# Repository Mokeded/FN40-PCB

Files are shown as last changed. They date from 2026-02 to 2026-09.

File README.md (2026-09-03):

# FN40 PCB

KiCad PCB design for the **FN40**, a hotswap 40%-style mechanical keyboard (internal project name `4060`).

## Contents

- `4060.kicad_pro` / `4060.kicad_sch` / `4060.kicad_pcb` — KiCad project, schematic, and board files
- `4060.kicad_prl` — KiCad project local settings
- `4060.json` — layout/keyboard-layout-editor data
- `4060.svg` — rendered board image
- `4060.round-tracks-config` — config for the KiCad round-tracks plugin
- `4060-backups/` — autosaved backups of the board file
- `footprints/Switch_Keyboard_Hotswap_Kailh.pretty/` — Kailh hotswap socket footprint library
- `acheron_Components.pretty-master/`, `acheron_Connectors.pretty-master/` — third-party footprint libraries from [Acheron](https://github.com/acheron-project) (also kept as `.zip` archives)
- `random-keyboard-parts.pretty/` — additional footprint library
- `fp-lib-table` / `fp-info-cache` — KiCad footprint library table and cache
- `fabrication-toolkit-options.json` — settings for the [KiCad Fabrication Toolkit](https://github.com/bennymeg/kicad-fabrication-toolkit) plugin used to generate manufacturing files
- `freerouting.dsn` / `temp-freerouting.dsn` — Specctra DSN exports for autorouting with [Freerouting](https://github.com/freerouting/freerouting)
- `kbplacer.log` — log output from the [KiCad KBPlacer](https://github.com/adamws/kicad-kbplacer) plugin used for switch placement
- `production/` — generated manufacturing outputs, including `4060.zip` (Gerbers/drill files), `bom.csv` (bill of materials), `positions.csv` (pick-and-place data), `designators.csv`, and `netlist.ipc`

## Getting started

1. Install [KiCad](https://www.kicad.org/) (developed with KiCad 7/8).
2. Open `4060.kicad_pro` in KiCad.
3. Footprint libraries referenced by `fp-lib-table` are included in this repo — no extra setup should be required.

## Fabrication

Manufacturing-ready files (Gerbers, drill files, BOM, and pick-and-place data) are available in `production/`. These were generated with the KiCad Fabrication Toolkit plugin; re-run it after any board changes to refresh the outputs.

## Credits

- Footprint libraries by [Acheron](https://github.com/acheron-project)
- Hotswap socket footprints from the [Switch_Keyboard_Hotswap_Kailh](https://github.com/) footprint library

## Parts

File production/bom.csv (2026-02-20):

Designator | Footprint | Quantity | Value | LCSC Part #
C1, C3, C4, C5, C6, C7 | 0402 | 6 | 100nF | C307331
C2 | 0402 | 1 | 4.7uF | C23733
C8, C9 | 0402 | 2 | 1uF | C52923
D1, D10, D11, D12, D13, D14, D15, D16, D17, D18, D19, D2, D20, D21, D22, D23, D24, D25, D26, D27, D28, D29, D3, D30, D31, D32, D33, D34, D35, D36, D37, D38, D39, D4, D40, D41, D42, D43, D44, D45, D46, D47, D48, D49, D5, D50, D51, D52, D53, D54, D55, D56, D57, D6, D7, D8, D9 | D_SOD-123F | 57 | D
J1 | MOLEX_781710004_MountingReliefs | 1 | JST | C588524
R1 | 0402 | 1 | 10k | C25744
SW1, SW10, SW11, SW13, SW14, SW15, SW16, SW17, SW18, SW19, SW2, SW20, SW21, SW22, SW25, SW26, SW27, SW28, SW29, SW3, SW30, SW31, SW32, SW33, SW34, SW37, SW38, SW39, SW4, SW40, SW41, SW42, SW43, SW44, SW45, SW46, SW5, SW50, SW51, SW55, SW56_1, SW6, SW7, SW8, SW9 | SW_Hotswap_Kailh_MX_Plated_1.00u | 45 | SW_Push
SW12, SW23, SW48, SW49, SW56, SW57 | SW_Hotswap_Kailh_MX_Plated_1.50u | 6 | SW_Push
SW24 | SW_Hotswap_Kailh_MX_Plated_1.75u_90deg | 1 | SW_Push
SW24_1 | SW_Hotswap_Kailh_MX_Plated_1.25u_90deg | 1 | SW_Push
SW35, SW36, SW48_1, SW57_1 | SW_Hotswap_Kailh_MX_Plated_1.25u | 4 | SW_Push
SW35_1 | SW_Hotswap_Kailh_MX_Plated_ISOEnter_270deg | 1 | SW_Push
SW35_2, SW36_1, SW54 | SW_Hotswap_Kailh_MX_Plated_2.25u | 3 | SW_Push
SW47 | SW_Hotswap_Kailh_MX_Plated_1.75u | 1 | SW_Push
SW47_1, SW52 | SW_Hotswap_Kailh_MX_Plated_2.75u | 2 | SW_Push
SW53 | SW_Hotswap_Kailh_MX_Plated_7.00u | 1 | SW_Push
SW58, SW59 | SW_SPST_SKQG_WithoutStem | 2 | RST | C318884
U1 | LQFP-48_7x7mm_P0.5mm | 1 | STM32F072C8Tx | C80488
U2 | SOT-23 | 1 | XC6206PxxxMR-Regulator_Linear | C5446

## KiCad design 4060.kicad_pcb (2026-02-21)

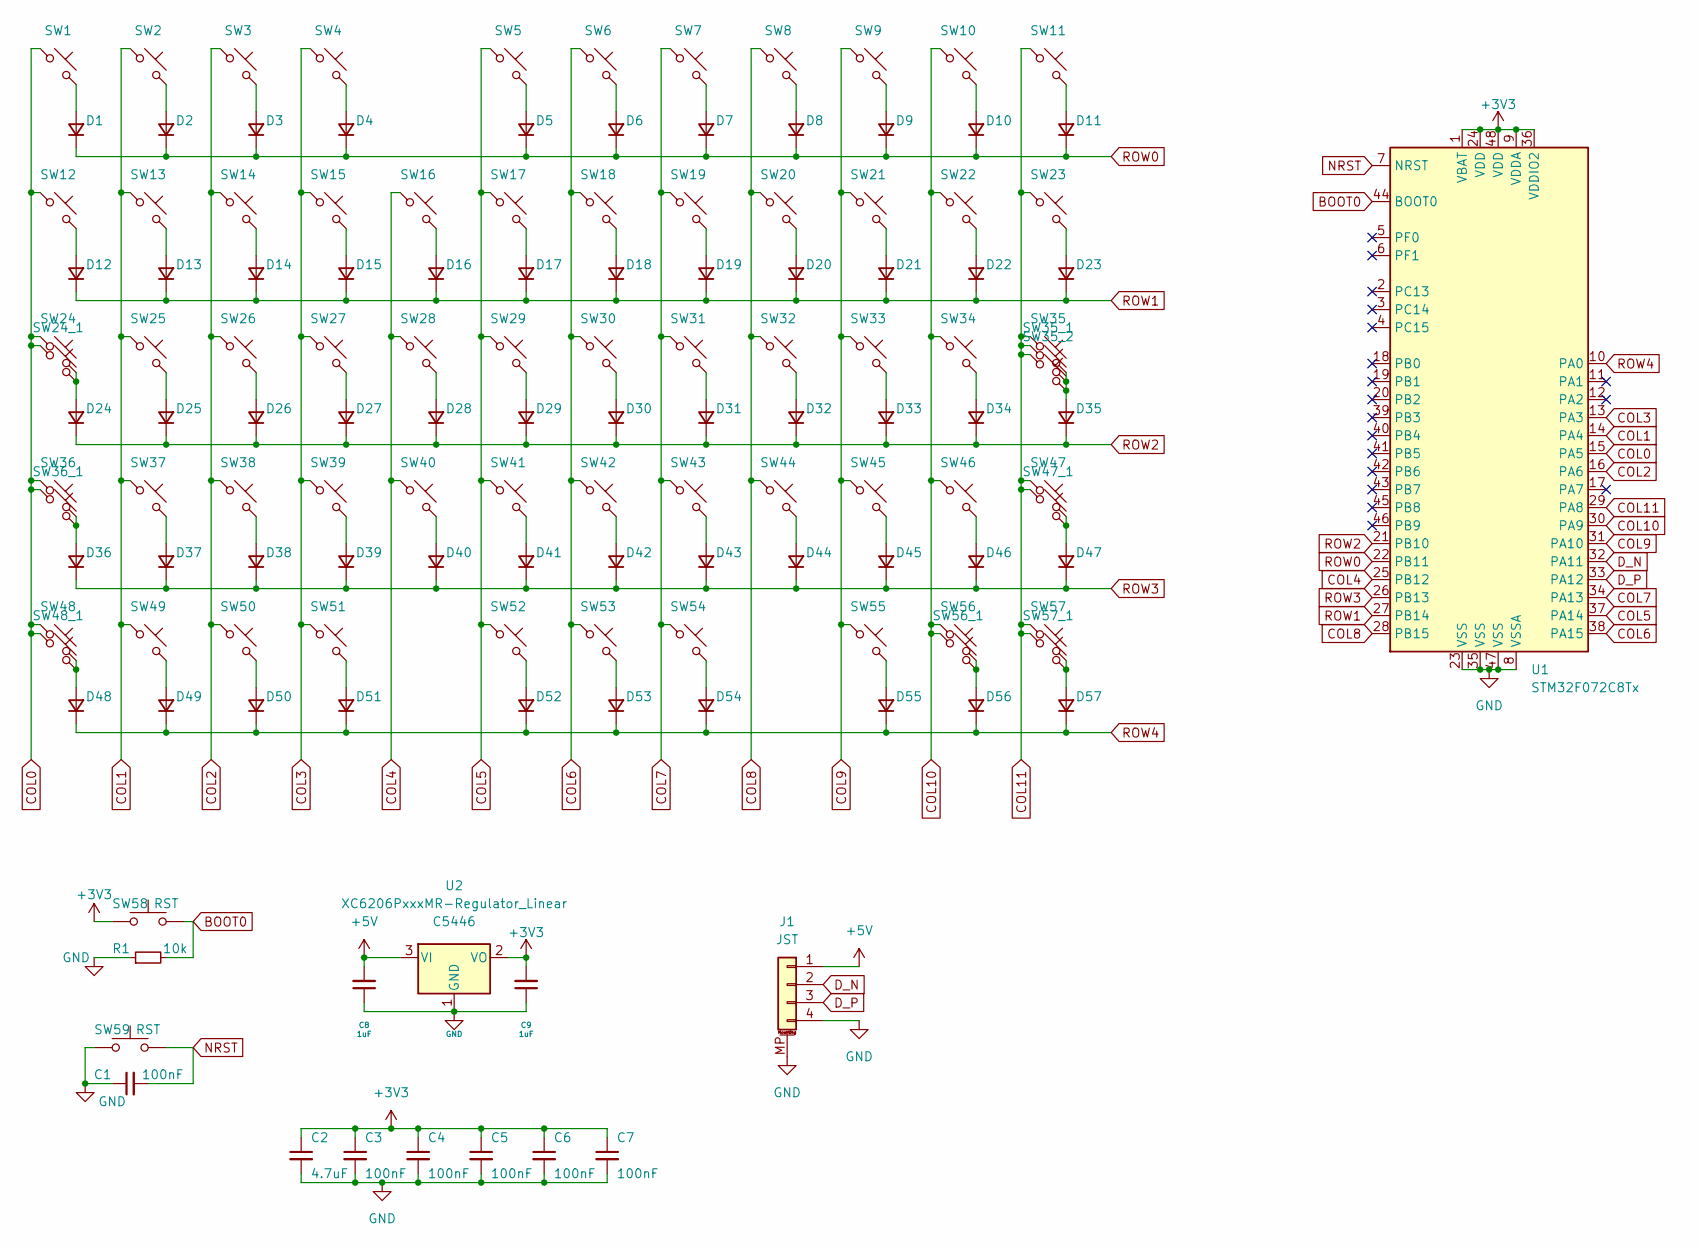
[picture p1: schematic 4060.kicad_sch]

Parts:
C1, C3, C4, C5, C6, C7: 100nF; C_0402_1005Metric; LCSC C307331
C2: 4.7uF; C_0402_1005Metric; LCSC C23733
C8, C9: 1uF; C_0402_1005Metric; LCSC C52923
D1, D2, D3, D4, D5, D6, D7, D8, D9, D10, D11, D12, D13, D14, D15, D16, D17, D18, D19, D20, D21, D22, D23, D24, D25, D26, D27, D28, D29, D30, D31, D32, D33, D34, D35, D36, D37, D38, D39, D40, D41, D42, D43, D44, D45, D46, D47, D48, D49, D50, D51, D52, D53, D54, D55, D56, D57: D; D_SOD-123F
J1: JST; MOLEX_781710004_MountingReliefs; LCSC C588524
R1: 10k; R_0402_1005Metric; LCSC C25744
SW1, SW2, SW3, SW4, SW5, SW6, SW7, SW8, SW9, SW10, SW11, SW13, SW14, SW15, SW16, SW17, SW18, SW19, SW20, SW21, SW22, SW25, SW26, SW27, SW28, SW29, SW30, SW31, SW32, SW33, SW34, SW37, SW38, SW39, SW40, SW41, SW42, SW43, SW44, SW45, SW46, SW50, SW51, SW55, SW56_1: SW_Push; SW_Hotswap_Kailh_MX_Plated_1.00u
SW12, SW23, SW48, SW49, SW56, SW57: SW_Push; SW_Hotswap_Kailh_MX_Plated_1.50u
SW24: SW_Push; SW_Hotswap_Kailh_MX_Plated_1.75u_90deg
SW24_1: SW_Push; SW_Hotswap_Kailh_MX_Plated_1.25u_90deg
SW35, SW36, SW48_1, SW57_1: SW_Push; SW_Hotswap_Kailh_MX_Plated_1.25u
SW35_1: SW_Push; SW_Hotswap_Kailh_MX_Plated_ISOEnter_270deg
SW35_2, SW36_1, SW54: SW_Push; SW_Hotswap_Kailh_MX_Plated_2.25u
SW47: SW_Push; SW_Hotswap_Kailh_MX_Plated_1.75u
SW47_1, SW52: SW_Push; SW_Hotswap_Kailh_MX_Plated_2.75u
SW53: SW_Push; SW_Hotswap_Kailh_MX_Plated_7.00u
SW58, SW59: RST; SW_SPST_SKQG_WithoutStem; LCSC C318884
U1: STM32F072C8Tx; LQFP-48_7x7mm_P0.5mm; LCSC C80488
U2: XC6206PxxxMR-Regulator_Linear; SOT-23; LCSC C5446

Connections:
+3V3: C2.1, C3.1, C4.1, C5.1, C6.1, C7.1, C9.2, SW58.1, U1.1 (VBAT), U1.9 (VDDA), U1.24 (VDD), U1.36 (VDDIO2), U1.48 (VDD), U2.2 (VO)
+5V: C8.2, J1.1, U2.3 (VI)
BOOT0: R1.2, SW58.2, U1.44 (BOOT0)
COL0: SW1.1, SW12.1, SW24.1, SW24_1.1, SW36.1, SW36_1.1, SW48.1, SW48_1.1, U1.15 (PA5)
COL1: SW2.1, SW13.1, SW25.1, SW37.1, SW49.1, U1.14 (PA4)
COL2: SW3.1, SW14.1, SW26.1, SW38.1, SW50.1, U1.16 (PA6)
COL3: SW4.1, SW15.1, SW27.1, SW39.1, SW51.1, U1.13 (PA3)
COL4: SW16.1, SW28.1, SW40.1, U1.25 (PB12)
COL5: SW5.1, SW17.1, SW29.1, SW41.1, SW52.1, U1.37 (PA14)
COL6: SW6.1, SW18.1, SW30.1, SW42.1, SW53.1, U1.38 (PA15)
COL7: SW7.1, SW19.1, SW31.1, SW43.1, SW54.1, U1.34 (PA13)
COL8: SW8.1, SW20.1, SW32.1, SW44.1, U1.28 (PB15)
COL9: SW9.1, SW21.1, SW33.1, SW45.1, SW55.1, U1.31 (PA10)
COL10: SW10.1, SW22.1, SW34.1, SW46.1, SW56.1, SW56_1.1, U1.30 (PA9)
COL11: SW11.1, SW23.1, SW35.1, SW35_1.1, SW35_2.1, SW47.1, SW47_1.1, SW57.1, SW57_1.1, U1.29 (PA8)
D_N: J1.2, U1.32 (PA11)
D_P: J1.3, U1.33 (PA12)
GND: C1.1, C2.2, C3.2, C4.2, C5.2, C6.2, C7.2, C8.1, C9.1, J1.4, J1.MP (MountPin), R1.1, SW59.1, U1.8 (VSSA), U1.23 (VSS), U1.35 (VSS), U1.47 (VSS), U2.1 (GND)
NRST: C1.2, SW59.2, U1.7 (NRST)
unnamed: D1.2 (A), SW1.2
unnamed: D2.2 (A), SW2.2
unnamed: D3.2 (A), SW3.2
unnamed: D4.2 (A), SW4.2
unnamed: D5.2 (A), SW5.2
unnamed: D6.2 (A), SW6.2
unnamed: D7.2 (A), SW7.2
unnamed: D8.2 (A), SW8.2
unnamed: D9.2 (A), SW9.2
unnamed: D10.2 (A), SW10.2
unnamed: D11.2 (A), SW11.2
unnamed: D12.2 (A), SW12.2
unnamed: D13.2 (A), SW13.2
unnamed: D14.2 (A), SW14.2
unnamed: D15.2 (A), SW15.2
unnamed: D16.2 (A), SW16.2
unnamed: D17.2 (A), SW17.2
unnamed: D18.2 (A), SW18.2
unnamed: D19.2 (A), SW19.2
unnamed: D20.2 (A), SW20.2
unnamed: D21.2 (A), SW21.2
unnamed: D22.2 (A), SW22.2
unnamed: D23.2 (A), SW23.2
unnamed: D24.2 (A), SW24.2, SW24_1.2
unnamed: D25.2 (A), SW25.2
unnamed: D26.2 (A), SW26.2
unnamed: D27.2 (A), SW27.2
unnamed: D28.2 (A), SW28.2
unnamed: D29.2 (A), SW29.2
unnamed: D30.2 (A), SW30.2
unnamed: D31.2 (A), SW31.2
unnamed: D32.2 (A), SW32.2
unnamed: D33.2 (A), SW33.2
unnamed: D34.2 (A), SW34.2
unnamed: D35.2 (A), SW35.2, SW35_1.2, SW35_2.2
unnamed: D36.2 (A), SW36.2, SW36_1.2
unnamed: D37.2 (A), SW37.2
unnamed: D38.2 (A), SW38.2
unnamed: D39.2 (A), SW39.2
unnamed: D40.2 (A), SW40.2
unnamed: D41.2 (A), SW41.2
unnamed: D42.2 (A), SW42.2
unnamed: D43.2 (A), SW43.2
unnamed: D44.2 (A), SW44.2
unnamed: D45.2 (A), SW45.2
unnamed: D46.2 (A), SW46.2
unnamed: D47.2 (A), SW47.2, SW47_1.2
unnamed: D48.2 (A), SW48.2, SW48_1.2
unnamed: D49.2 (A), SW49.2
unnamed: D50.2 (A), SW50.2
unnamed: D51.2 (A), SW51.2
unnamed: D52.2 (A), SW52.2
unnamed: D53.2 (A), SW53.2
unnamed: D54.2 (A), SW54.2
unnamed: D55.2 (A), SW55.2
unnamed: D56.2 (A), SW56.2, SW56_1.2
unnamed: D57.2 (A), SW57.2, SW57_1.2
ROW0: D1.1 (K), D2.1 (K), D3.1 (K), D4.1 (K), D5.1 (K), D6.1 (K), D7.1 (K), D8.1 (K), D9.1 (K), D10.1 (K), D11.1 (K), U1.22 (PB11)
ROW1: D12.1 (K), D13.1 (K), D14.1 (K), D15.1 (K), D16.1 (K), D17.1 (K), D18.1 (K), D19.1 (K), D20.1 (K), D21.1 (K), D22.1 (K), D23.1 (K), U1.27 (PB14)
ROW2: D24.1 (K), D25.1 (K), D26.1 (K), D27.1 (K), D28.1 (K), D29.1 (K), D30.1 (K), D31.1 (K), D32.1 (K), D33.1 (K), D34.1 (K), D35.1 (K), U1.21 (PB10)
ROW3: D36.1 (K), D37.1 (K), D38.1 (K), D39.1 (K), D40.1 (K), D41.1 (K), D42.1 (K), D43.1 (K), D44.1 (K), D45.1 (K), D46.1 (K), D47.1 (K), U1.26 (PB13)
ROW4: D48.1 (K), D49.1 (K), D50.1 (K), D51.1 (K), D52.1 (K), D53.1 (K), D54.1 (K), D55.1 (K), D56.1 (K), D57.1 (K), U1.10 (PA0)

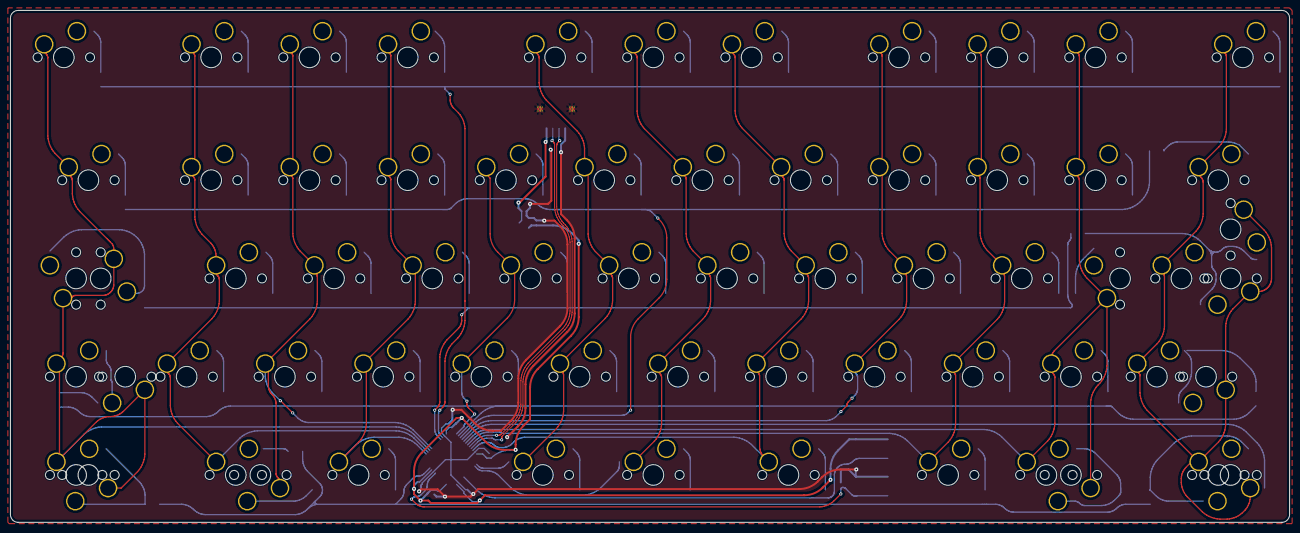
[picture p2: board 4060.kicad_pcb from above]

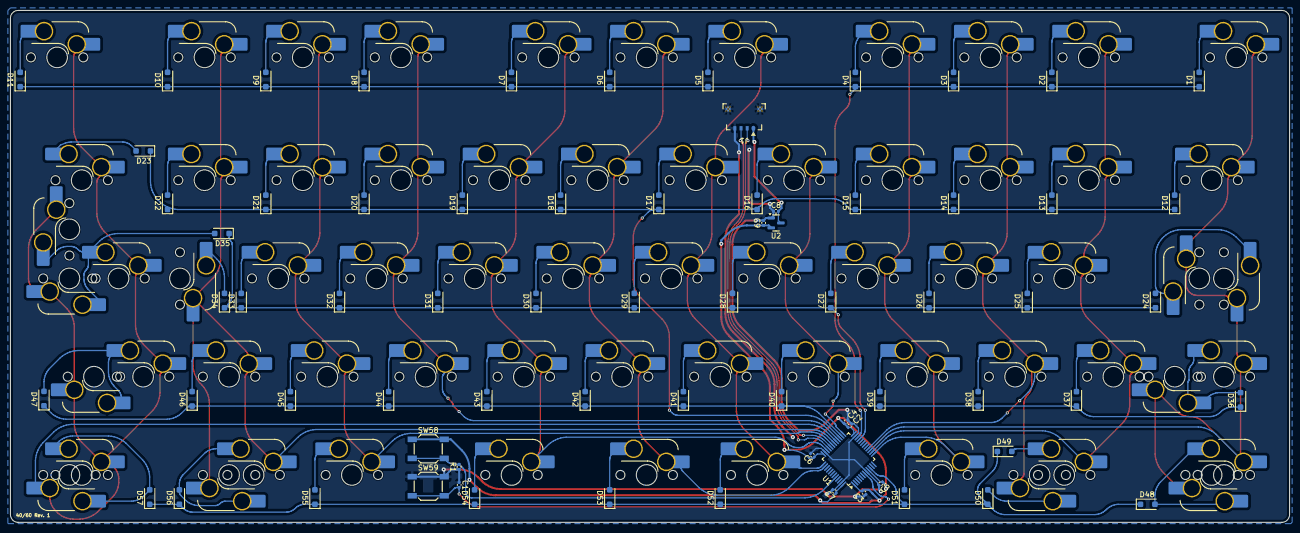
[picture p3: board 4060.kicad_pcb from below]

Board: 2 copper layers, 248.0 x 99.2 mm, 137 parts (72 on the bottom side), 81 nets.

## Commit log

2026-02-19 Added MCU, ESD, and some routing
    [TKL 40.kicad_pcb, TKL 40.kicad_sch]
2026-02-20 Finished PCB
    [4060.kicad_pcb, 4060.kicad_sch, TKL 40.kicad_pcb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]
2026-02-21 Routing fixes
    [4060.kicad_pcb]
